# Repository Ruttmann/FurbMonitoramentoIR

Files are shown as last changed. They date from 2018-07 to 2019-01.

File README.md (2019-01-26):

# PDGE4

This project comprises only the hardware programming and schematics. For server-side code, see https://github.com/Ruttmann/FurbMonitoramentoWEB

## This project is a device based on ATMega 2560 that has the capabilities to:
- Receive an IR signal from a remote controller (TV, ar-conditioner, etc.);
- Send it to a external server;
- Monitors the status of an equipment (turned on, off);
- Communicates to the server when the status changes, retrieving via Internet the learned signal to turn on/off the equipment.
- Emit those IR signals, turning on/off the equipments in the room.

The server can have infinite IR signals decodified and stored, and has a simple web interface for:
- Monitor availability of the devices that joined to him;
- Monitor possible operation failures of the devices (during the status monitoring of the equipments);
- Issue a command to one or more devices (TO BE DEVELOPED);
- Assign IR signals to devices, making possible to change devices between rooms, for example.

## Main hardware used:
- Arduino ATMega 2560;
- Ethernet Shield W5100;
- IR receptor;
- IR emitter diodes;
- Common electronic components (see schematic on project files).

## External Dependencies

- [Socket.io-v1.x-Library](https://github.com/washo4evr/Socket.io-v1.x-Library)
- [Arduino-IRremote](https://github.com/z3t0/Arduino-IRremote)
- [ArduinoJson](https://github.com/bblanchon/ArduinoJson)

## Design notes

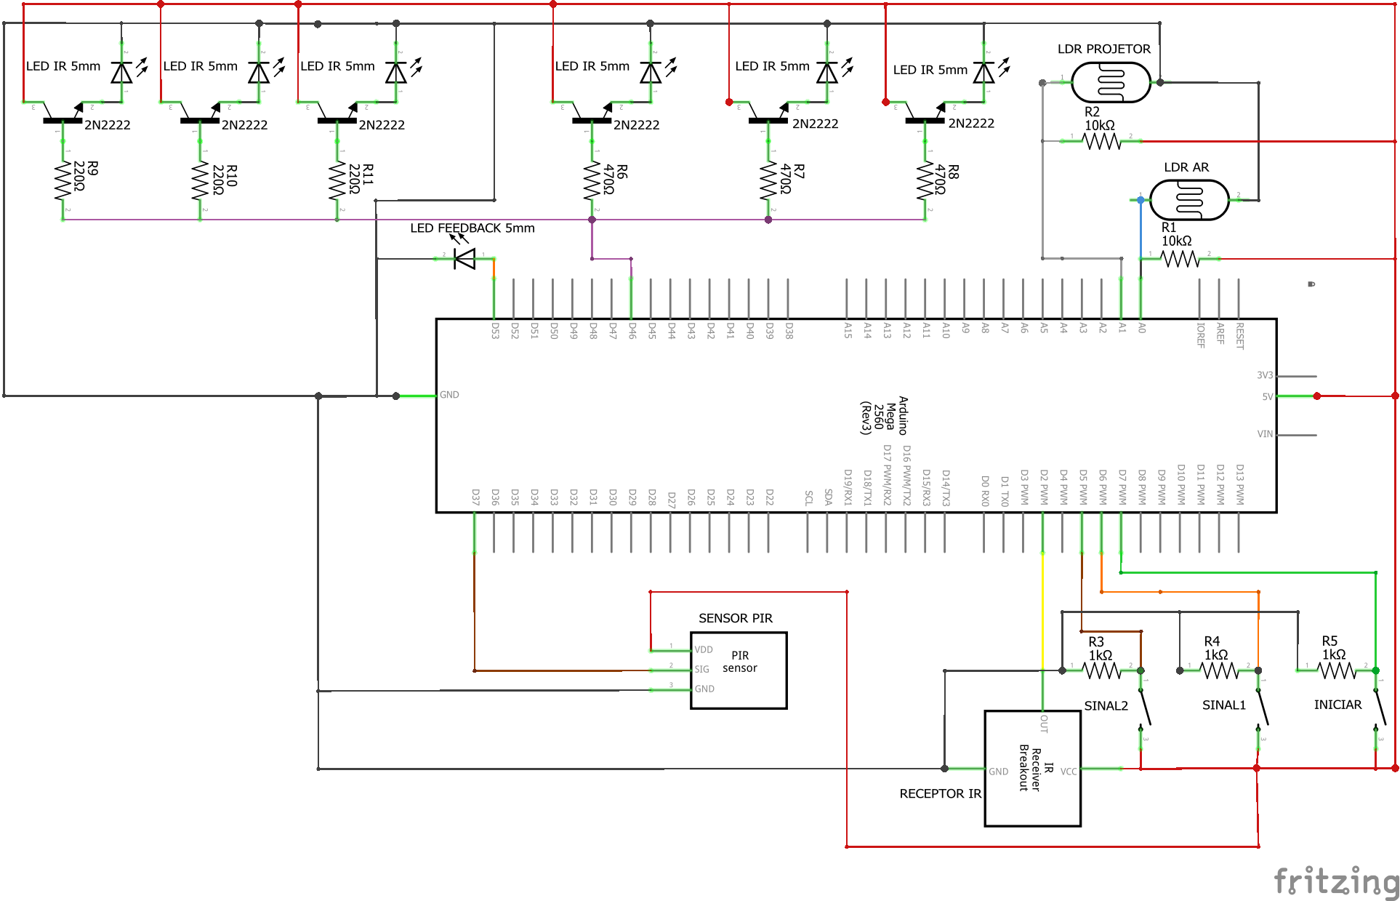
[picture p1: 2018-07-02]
hardware_schema/PDGE4_schem.png

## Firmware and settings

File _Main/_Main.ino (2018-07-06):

/*
 * Definições de comunicação
 */
#include <SocketIOClient.h>
#include <ArduinoJson.h>
#include <Ethernet.h>
#include <SPI.h>

/*
 * Definições de IR
 * Conexões:
 *  V+           ->  +5v
 *  GND          ->  GND
 *  Signal In    ->  Pino digital 2 (padrão biblioteca IRremote)
 *  Signal Out   ->  Pino digital 46 (customizado na biblioteca IRremote)
 */
#include <IRremote.h>
#define MAX_LENGTH 500 //Tamanho do trem de pulsos
#define FREQ 38 //Frequência da portadora em KHz

/*
 * Definições de boot
 */
#define PIN_INICIAR 7 //Pino digital iniciar operação
#define PIN_CAD1 6 //Pino digital cadastrar sinal 1
#define PIN_CAD2 5 //Pino digital cadastrar sinal 2

/*
 * Definições de monitoramento 
 */
#define PIN_PIR 37 //Pino digital do sensor de presença
#define PIN_LDR_AR 0 //Pino analógico A0 do sensor LDR ar-condicionado
#define PIN_LDR_PR 1 //Pino analógico A1 do sensor LDR projetor
#define PIN_LED_FDB 53 //Pino digital do led de status de inicialização do sensor PIR

/*
 * Constantes e variáveis de comunicação
 */
SocketIOClient client; //Instância do cliente websocket
const byte mac[] = { 0xAA, 0x00, 0xBE, 0xEF, 0xFE, 0xEE }; //MAC Address do Ethernet Shield
const char hostname[] = "pdge4-furb.herokuapp.com"; //Hostname do servidor
//const char hostname[] = "192.168.0.15"; //Hostname do servidor
const int port = 3000; //Porta para conexão ao servidor (Não obrigatório)
const char nameSpace[] = "arduino"; //Namespace no servidor websocket
const char identificador[] = "S111"; //Identificador do dispositivo
extern String RID; //Guarda o Id das mensagens recebidas do servidor
extern String Rname; //Guarda o SubId das mensagens recebidas do servidor
extern String Rcontent; //Guarda o conteúdo das mensagens recebidas do servidor
unsigned long contKeepAlive = 0; //Contador para envio de mensagem keepAlive

/*
 * Variáveis de IR
 */
IRsend irsend; //Emissor de IR
volatile unsigned int irBuffer[MAX_LENGTH]; //Armazena os pulsos temporariamente
volatile unsigned int x = 0; //Contador de pulsos armazenados no irBuffer
unsigned int sinalIR1[MAX_LENGTH]; //Armazena os tempos dos pulsos do sinal 1
unsigned int tamanhoSinal1; //Armazena a quantidade de pulsos do sinal 1
unsigned int sinalIR2[MAX_LENGTH]; //Armazena os tempos dos pulsos do sinal 2
unsigned int tamanhoSinal2; //Armazena a quantidade de pulsos do sinal 2

/*
 * Variáveis de monitoramento
 */
unsigned int ldrAr; //Valor do sensor LDR do ar-condicionado
unsigned int ldrPr; //Valor do sensor LDR do projetor
unsigned int statusPIR; //Status do sensor PIR
bool contadorIniciado = false; //Controle de inicialização do contador
unsigned long tempoContador = 0; //Contador de tempo sem detecções
bool salaVazia = false; //Flag de controle das modalidades de monitoramento

/*
 * Botões
 */
unsigned int btnCad1; //Cadastrar sinal 1
unsigned int btnCad2; //Cadastrar sinal 2
unsigned int btnIniciar; //Iniciar operação

/*
 * Flags gerais
 */
bool novoSinal1 = false; //TRUE se for cadastrado novo sinal 1
bool novoSinal2 = false; //TRUE se for cadastrado novo sinal 2
bool rodouBoot = false; //Controle de boot e execução

void setup() {
  Serial.begin(9600);
  boot();
}

void loop() {
  if (salaVazia) {
    monitoraSalaVazia();
  } else {
    enviarKeepAlive();
    monitoraSalaCheia();
  }
}

/*
 * Rotinas de boot do Arduino
 */
void boot() {
  pinMode(PIN_CAD1, INPUT);
  pinMode(PIN_CAD2, INPUT);
  pinMode(PIN_INICIAR, INPUT);
  pinMode(PIN_PIR, INPUT);
  pinMode(PIN_LED_FDB, OUTPUT);
  bool bootConcluido = false;

  while (!bootConcluido) {
    btnCad1 = digitalRead(PIN_CAD1);
    btnCad2 = digitalRead(PIN_CAD2);
    btnIniciar = digitalRead(PIN_INICIAR);

    if (btnCad1) { //Cadastrar sinal ar-condicionado
      Serial.println(F("Cadastrar sinal ar-condicionado"));
      setupIR();
      loopIR(true);
    } else if (btnCad2) { //Cadastrar sinal projetor
      Serial.println(F("Cadastrar sinal projetor"));
      setupIR();
      loopIR(false);
    }

    if (btnIniciar) { //Finaliza boot e inicia monitoramento
      setupComunicacao();
      if (novoSinal1) {
        int *sinais = sinalIR1;
        geraJSONsinais(tamanhoSinal1, sinais);
      }
      if (novoSinal2) {
        int *sinais = sinalIR2;
        geraJSONsinais(tamanhoSinal2, sinais);
      }
      zerarArraysIR();
      bootConcluido = true;
      delay(3000);
      Serial.println(F("Fim do boot..."));
      enviarMensagem("endBoot", "msg", "start");
      Serial.println(F("Iniciando monitoramento..."));
    }
  }
  rodouBoot = true;
}

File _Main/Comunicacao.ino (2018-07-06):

/*
 * Métodos para comunicação com o servidor remoto
 */

void setupComunicacao() {
  ficarOnline();
  conectarServidor();  
}

void ficarOnline() {
  Serial.println(F("Aguardando IP..."));
  if (!Ethernet.begin(mac)) {
    Serial.println(F("ERRO: Conexão Internet!"));
    erroFatal();
  } else {
    Serial.println(F("Online..."));
    Serial.println(Ethernet.localIP());
  }
}

void conectarServidor() {
  Serial.println(F("Conectando..."));
  if (!client.connect(hostname, nameSpace)) {
  //if (!client.connect(hostname, nameSpace, port)) {
    Serial.println(F("ERRO: Conexão Servidor!"));
    erroFatal();
  } else {
    Serial.println(F("Conectado ao servidor..."));
  }
  
  delay(2000);
  Serial.println(F("Enviando identificador de dispositivo..."));
  enviarMensagem("identify", "id", identificador);
  delay(2000);
}

void enviarKeepAlive() {
  if (contKeepAlive == 0) 
    contKeepAlive = millis();
    
  if ((millis() - contKeepAlive) >= 3000) {
    enviarMensagem("keepAlive", "msg", identificador);
    contKeepAlive = 0;
  } 
}

void desconectarServidor() {
  Serial.println(F("Fechando conexão..."));
  client.disconnect();
}

void ativarStandBy() {
  Serial.println(F("Entrando em stand-by..."));
  zerarArraysIR();
  desconectarServidor();
  delay(10000);
}

void geraJSONsinais(unsigned int tamanhoSinal, unsigned int* sinais) {
  unsigned int quantDivisoes = 0;
  bool ehMultiplo15 = false;
  unsigned int contadorSinal = 0;
  const char idMensagem[] = "arrayPart";
  
  if (tamanhoSinal%15 == 0) {
    quantDivisoes = tamanhoSinal/15;
    ehMultiplo15 = true;
  } else {
    quantDivisoes = tamanhoSinal/15+1;
    ehMultiplo15 = false;
  }

  enviarMensagem("sigSend", "msg", "start"); //Avisa ao servidor que vai começar a enviar sinais

  for (int i=1; i<=quantDivisoes; i++) { //Cada iteração gera um novo JSON
    StaticJsonBuffer<JSON_ARRAY_SIZE(15)> jb;
    JsonArray& arrayJSON = jb.createArray();
    if (ehMultiplo15) { //Quando o total de pulsos é múltiplo de 15
      for (int j=contadorSinal; j<contadorSinal+15; j++) {
        arrayJSON.add(sinais[j]);
      }
      arrayJSON.printTo(Serial);
      Serial.println(F("\n"));
      contadorSinal += 15;
      enviarJSON(idMensagem, arrayJSON);
    } else { //Quando o total de pulsos não é múltiplo de 15
      if (i < quantDivisoes) { //Entra aqui para gerar JSON de 15 elementos
        for (int k=contadorSinal; k<contadorSinal+15; k++) {
          arrayJSON.add(sinais[k]);
        }
        arrayJSON.printTo(Serial);
        Serial.println(F("\n"));
        contadorSinal += 15;
        enviarJSON(idMensagem, arrayJSON);
      } else { //Entra aqui para gerar o último JSON com < 15 elementos
        for (int l=contadorSinal; l<tamanhoSinal; l++) {
          arrayJSON.add(sinais[l]);
        }
        arrayJSON.printTo(Serial);
        Serial.println(F("\n"));
        enviarJSON(idMensagem, arrayJSON);
      }
    }
  }

   enviarMensagem("sigSend", "msg", "end"); //Avisa ao servidor que o envio de sinais terminou
}

void enviarJSON(char id[], JsonArray& json) {
  String jsonString;
  json.printTo(jsonString);
  
  if (client.connected()) {
    client.sendJSON(id, jsonString);
  } else {
    Serial.println(F("ERRO: Desconectado Servidor."));
    erroFatal();
  }
}

void enviarMensagem(char id[], char subId[], char conteudo[]) {
  if (client.connected()) {
    client.send(id, subId, conteudo);
  } else {
    Serial.println(F("ERRO: Desconectado Servidor."));
    erroFatal();
  }
}

bool recebeuMensagem(char id[], char subId[]) {
  if (client.monitor()) {
    return RID == id && Rname == subId;
  }
}

void notificaServidor() {
  if (!client.connected()) {
    Serial.println(F("Conexão perdida! Reconectando ao servidor..."));
    desconectarServidor();
    setupComunicacao();
  }
  
  enviarMensagem("monitoring", "msg", "emptyRoom");
  delay(2000);
  if (recebeuMensagem("monitoring", "msg") && Rcontent == "ok") {
    Serial.println(F("Desligamento autorizado!"));
    salaVazia = true;
    recebeSinal("send1");
    recebeSinal("send2");
    desligaDispositivos();
    ativarStandBy();
  } else {
    Serial.println(F("Fora do período de desligamento."));
  }
}

void recebeSinal(char idSinal[]) {
  unsigned int sinalIR[MAX_LENGTH];
  memset(sinalIR,0,sizeof(sinalIR));
  
  enviarMensagem("monitoring", "msg", idSinal);
  
  bool receiving = true;
  unsigned int indexArrayIR = 0;
  while (receiving) {
    delay(1000);
    if (recebeuMensagem("sP", "s")) {
      if (Rcontent == "eS") { //Acabaram os segmentos de sinal
        receiving = false;
      } else { //Recebeu um segmento de sinal
        DynamicJsonBuffer jb(JSON_ARRAY_SIZE(15) + 70);
        JsonArray& arrayJSON = jb.parseArray(Rcontent);
        //Debug
        Serial.println(">>>");
        Serial.println(idSinal);
        arrayJSON.printTo(Serial);
        Serial.println("");
        Serial.println("<<<");
        //Debug
        for (int i=0; i < arrayJSON.size(); i++) { //Preenche array temporário de sinais IR
          int value = arrayJSON[i];
          sinalIR[indexArrayIR] = value;
          indexArrayIR++;
        }

        enviarMensagem("monitoring", "msg", idSinal);
      }
    } 
  }
  
  for (int i=0; i < MAX_LENGTH; i++) { //Atribui valores do array temporário ao array de sinal principal
    if (idSinal == "send1")
      sinalIR1[i] = sinalIR[i];
    else
      sinalIR2[i] = sinalIR[i];
  }
}

void erroFatal() {
  while(true) {
    delay(100);
    digitalWrite(PIN_LED_FDB, HIGH); 
    delay(100);
    digitalWrite(PIN_LED_FDB, LOW);
  }
}

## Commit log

2018-04-11 adiciona as libs arduino e mais arquivos .ino
2018-04-11 adicionada a lib Socket.io para arduino
2018-04-11 removido exemplo Socket.io desnecessario
2018-04-13 adiciona pacote de desenvolvimento e organiza os diretorios
2018-04-20 Teste de tempo com PIR
2018-04-23 Adicionado exemplo de teste de sensor LDR
2018-04-23 Implementa métodos de monitoramento e revisa todos os comentários
2018-04-23 Adicionados métodos de comunicação
2018-04-28 Implementa segmentação e geração dos JSON de sinais
2018-04-30 Implementa envio de JSON testado 100% e limpeza de código
2018-04-30 Adiciona biblioteca ArduinoJson e atualiza bibliotecas existentes
2018-05-12 Implementa troca de mensagens com servidor p/ monitoramento
2018-05-14 Inicio implementação monitoramento/recepção de sinais
2018-05-30 Adiciona envio de mensagem ao server sinaliz. fim de boot
2018-06-08 Desenv. parcial lógica recebimento de sinais
2018-06-10 Refatora métodos de recepção de sinais
2018-06-20 Envio e recepção de sinais testado 100% local
2018-06-22 Testes de campo, falta acertar sensor PIR
2018-06-24 100% testado. - Resolve: timeout, monitoramento PIR, comunicação em geral. - Adiciona: rotina de stand-by que se ativa após desligar os equipamentos.
    [Comunicacao.ino, IR.ino, Monitoramento.ino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]
2018-06-25 Troca pino digital do sensor PIR
2018-06-25 Adiciona esquemas de hardware
    [PDGE4.fzz]
2018-06-25 Altera rotina que verificar status dos equipamentos
2018-06-26 Altera desligaDispositivos(): - Tenta desligar dispositivo no máximo 3 vezes. Se não desligar, emite ao servidor uma mensagem de falha.
2018-07-02 Adiciona mensagem restart e altera mensagem de cadastro de sinais.
    [PDGE4.fzz]
